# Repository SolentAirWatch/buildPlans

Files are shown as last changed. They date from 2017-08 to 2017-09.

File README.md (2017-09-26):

# buildPlans
build plans for sniffy and associated brackets. 

We're a little thin on documentation here - please help us out by submitting a pull request!

The works contained in this repositiory are licensed under the Creative Commons Attribution-NonCommercial-ShareAlike 4.0 International license (CC BY-NC-SA 4.0). This means you are free to share and share-alike for non-commercial use.




# Sniffy v1 Build Kit Assmebly

The sniffy kit containes the following: -

* 4x M4 x 12 barral bolts (#2)
* 4x M2 x 10 cheese head screws (#5)
* 4x self tapping screws (#3)
* 9x Nylon M3 x 10 cheese head screws 4x spacers (#1 & #6)
* 1x Back plate (drilled) (#7)
* 1x Enclosure (drilled) (not on photo)
* 1x 3D printed sensor cowling (#11)
* 1x Bosche BME280 environment sensor (temp, pressure, humdity) (#9)
* 1x Plantower PMS5003 Particulate Matter (PM) sensor (#10)
* 1x pi header to sensor cable

In addtion to the kit you will need:
* 1x Raspberry Pi Zero W
* Micro SD card (minimum 8 GB)
* Raspberry Pi Header (solderless headers are amvailable if you don't feel confident soldering)

These parts are shown in the photos below:
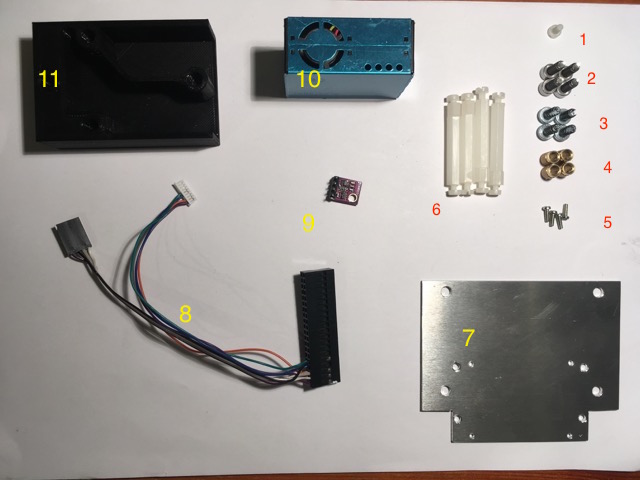
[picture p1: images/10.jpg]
Parts


* Insert the threads into the 3D printed sensor cowling 
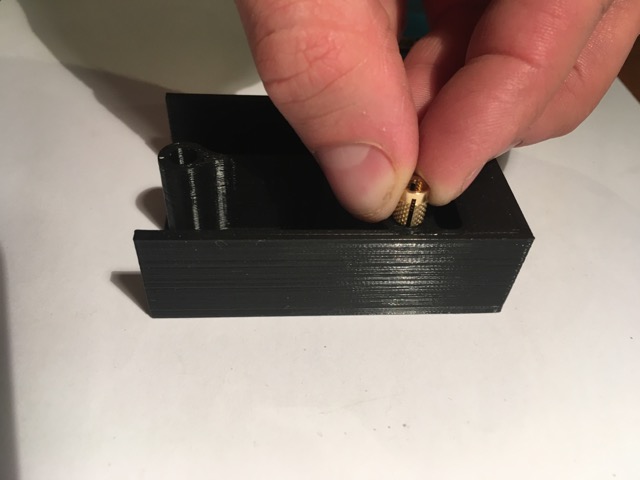
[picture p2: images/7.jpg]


* Use the M2 screws to mount the Pm sensor to the mounting place

* Use the nylon spacers and screws to mount the Raspbery Pi Zero above the PM sensor. You may need to widen the holes to 3mm but the nylon screws generally fit.

* Mount the assembly into the enclosure, fix the mounting plate using the self tapping screws

* Mount the BME280 sensor above the PM sensor using the remaining nylon screw into the threaded hole.
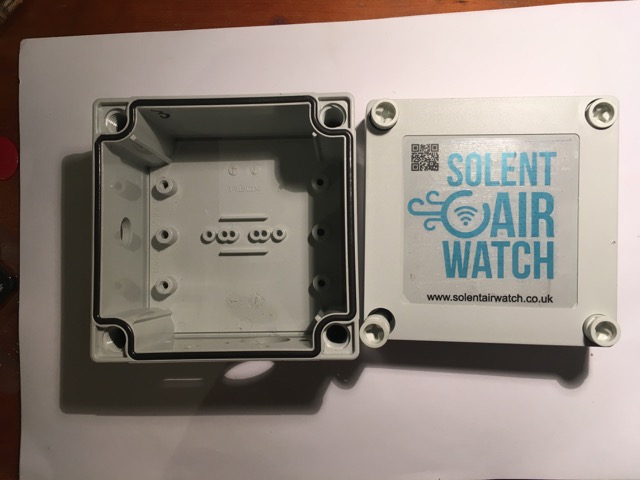
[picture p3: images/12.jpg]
box


* wire the sensor to the pi taking note of white marks denoting pin 1

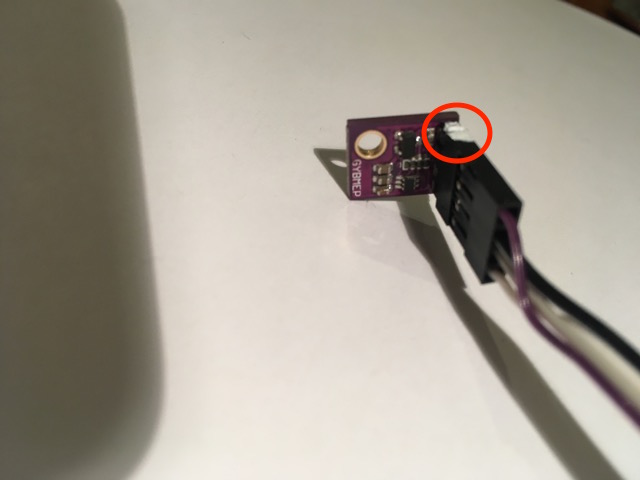
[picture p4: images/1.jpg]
BME280

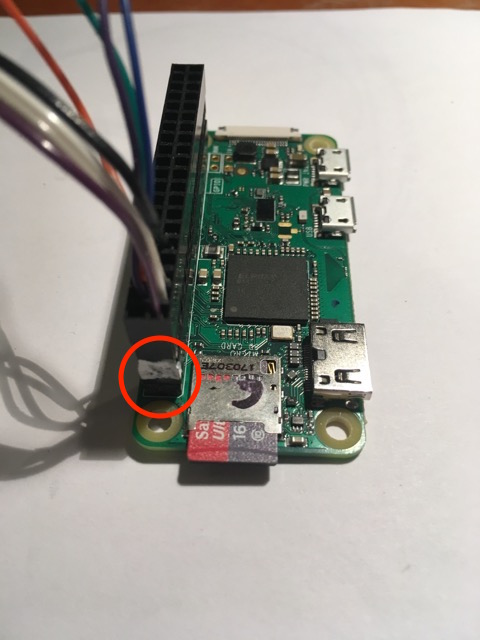
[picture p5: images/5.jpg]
RPi Header Pin 1


* Fit an SD card of at least 8GB and head over to /solentairwatcg/sniffy and follow the instructions to set up the raspberry pi and begin streaming data.

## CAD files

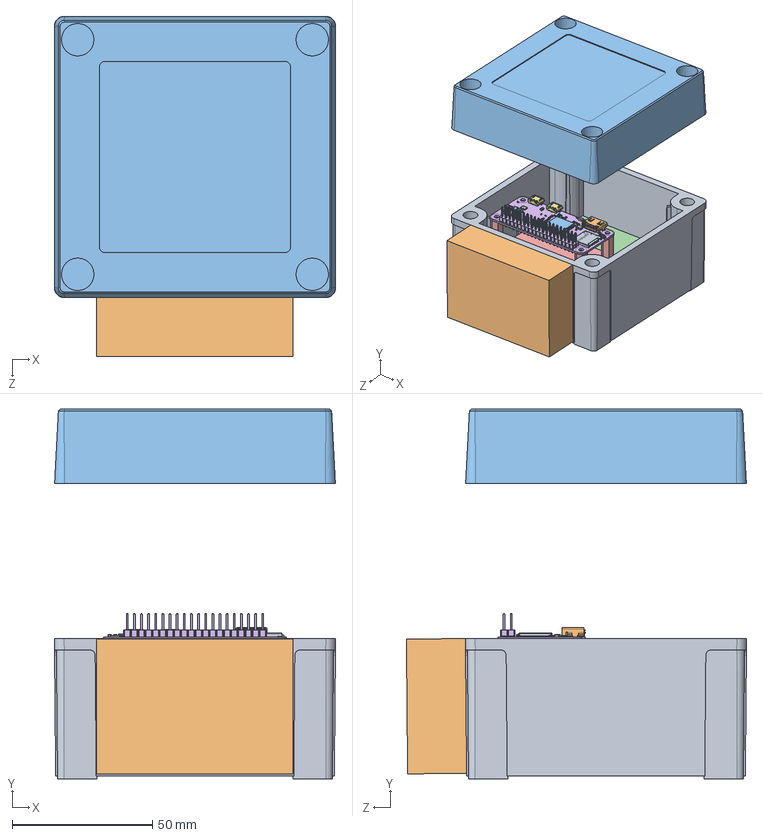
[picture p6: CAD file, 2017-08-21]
solidworks/sniffy_v1.SLDASM
100.1 x 131.7 x 121.1 mm
SNFY_003-FIBOX
SNFY_002-SensorCowling_2
SNFY_004-FIBOX-LID
SNFY005-backplate
SNF005 - pms5003
Raspberry_pizero_PCB
Micro USB_input_female (short)-SMT x 2
0204 - Capacitor x 34
0204- Resistor x 17
CAP-0306 x 2
Raspberry_pizero_BCM2835 with VC4
Crystal 3.4x2.4mm
32,768 Khz Crystal
0805- Capacitor x 7
0204 - Capacitor Brown x 8
6-Pin SOT
micro sd molex
hdmi type C
Voltage Regulator 3x3mm 12-Pin
1210 inductor x 3
SNFY009 - M3 hex standoff 36mm x 4
raspberry_pi_B+_(bar_180_2x20)

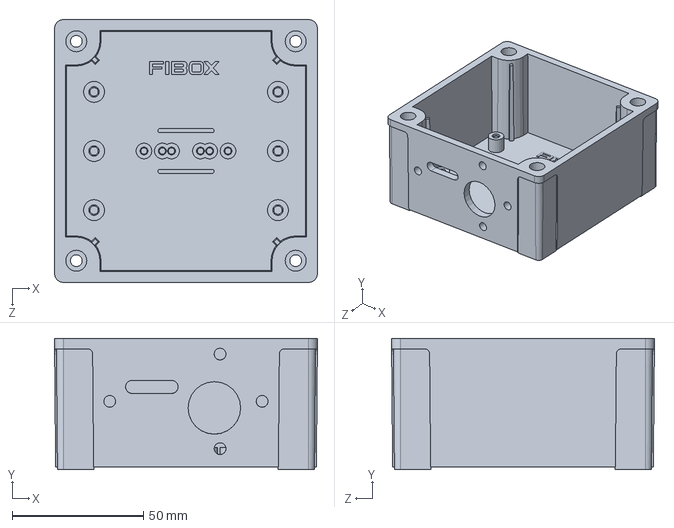
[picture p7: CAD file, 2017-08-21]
solidworks/SNFY_003-FIBOX.SLDPRT
100.1 x 50.0 x 100.1 mm

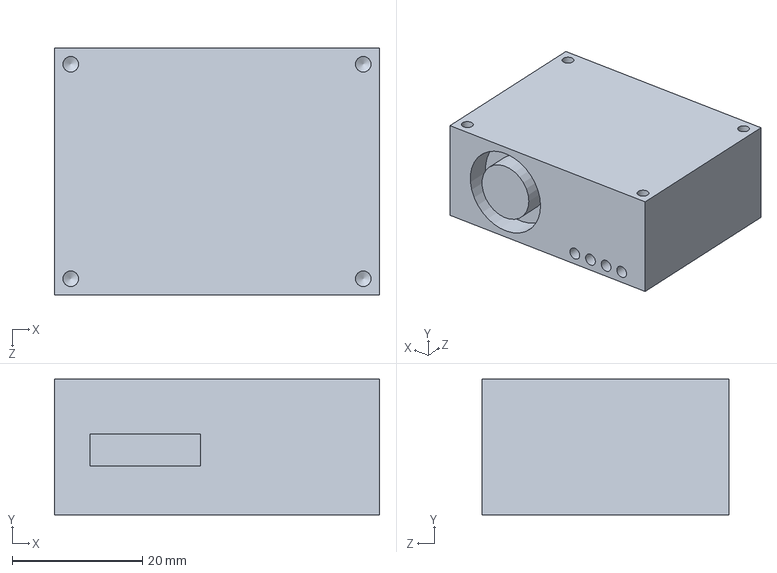
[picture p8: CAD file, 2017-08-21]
solidworks/SNF005 - pms5003.SLDPRT
50.0 x 20.9 x 38.0 mm

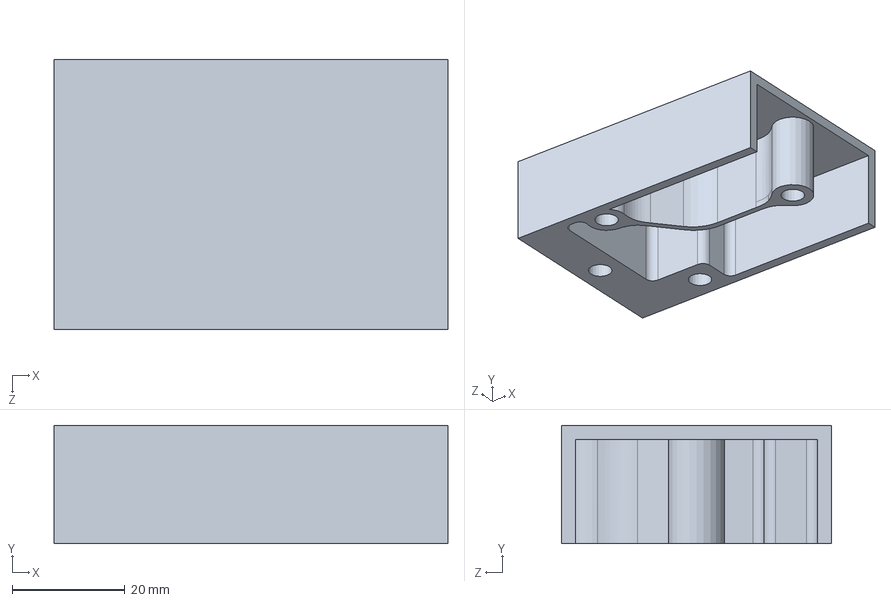
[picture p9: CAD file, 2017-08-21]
solidworks/SNFY_002-SensorCowling_2.SLDPRT
70.0 x 21.0 x 48.0 mm

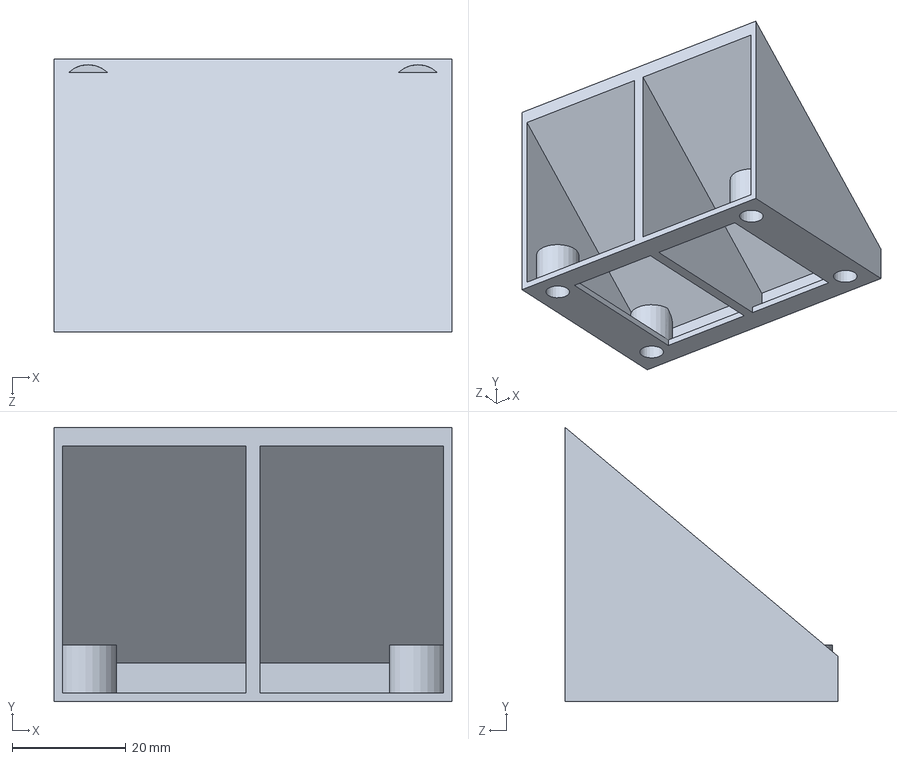
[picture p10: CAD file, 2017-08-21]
solidworks/SNFY_001-SensorCowling.SLDPRT
70.0 x 48.3 x 48.0 mm

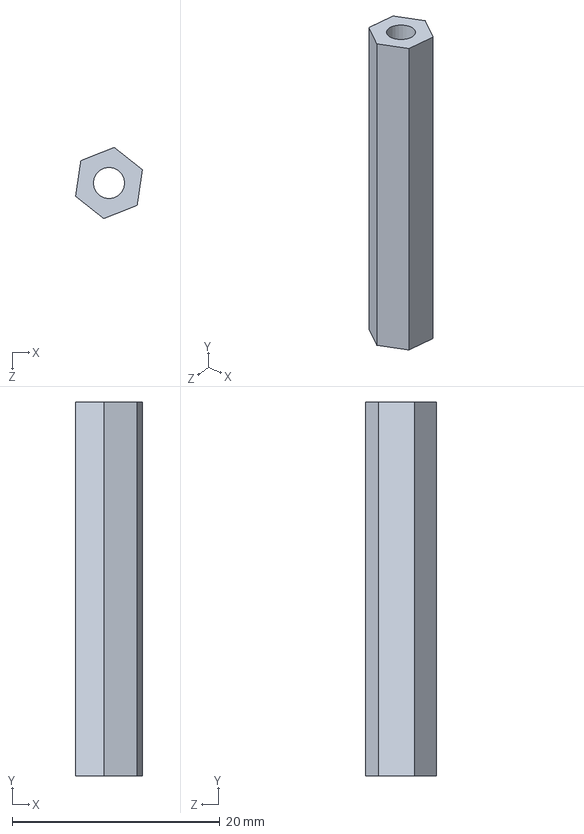
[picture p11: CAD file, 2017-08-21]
solidworks/SNFY009 - M3 hex standoff 26mm.SLDPRT
6.44 x 36.0 x 6.85 mm

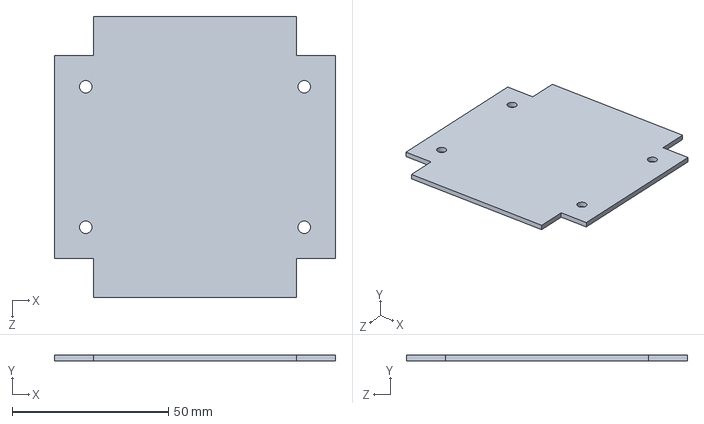
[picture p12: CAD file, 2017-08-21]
solidworks/SNFY005.SLDPRT
90.0 x 2.00 x 90.0 mm

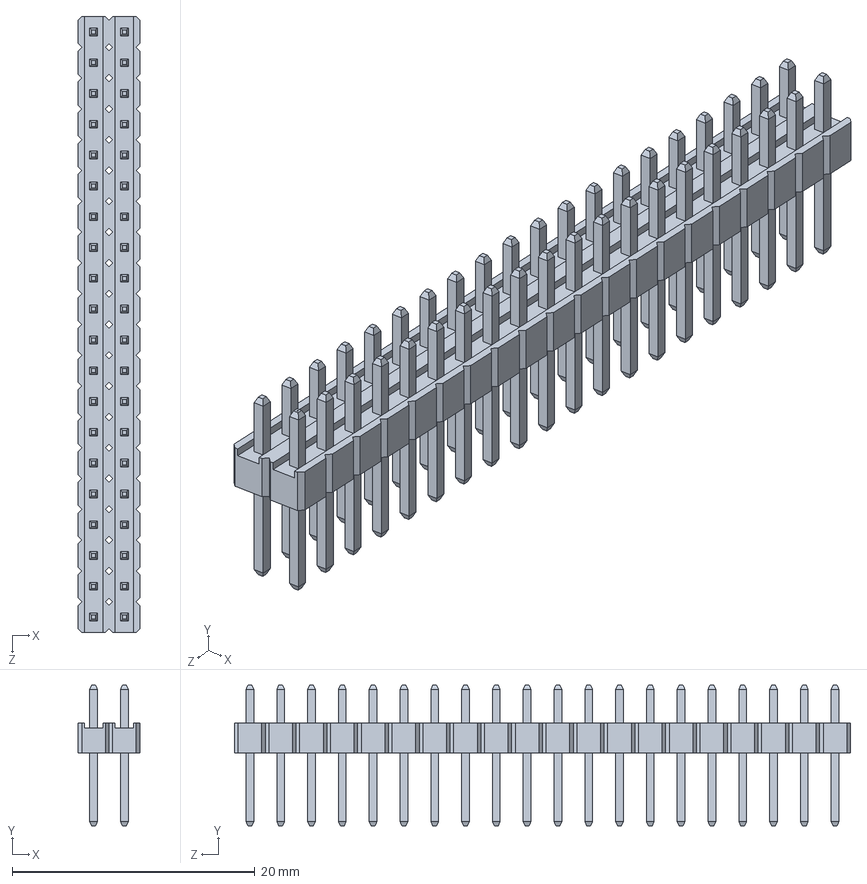
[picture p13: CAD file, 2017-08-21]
solidworks/raspberry_pi_B+_(bar_180_2x20).SLDPRT
5.08 x 11.6 x 50.8 mm

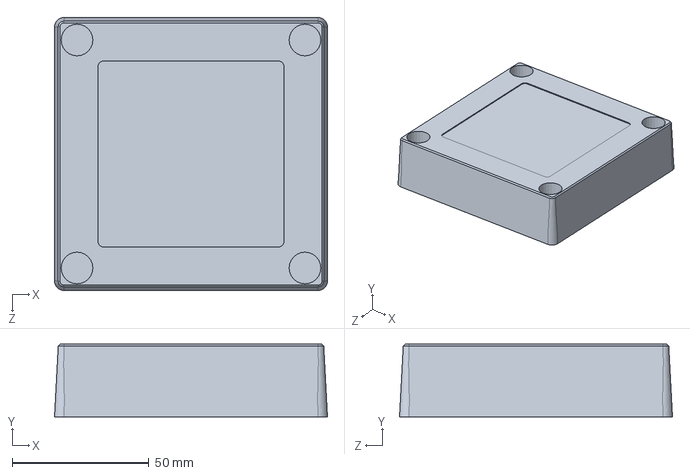
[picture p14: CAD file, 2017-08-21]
solidworks/SNFY_004-FIBOX-LID.SLDPRT
100.0 x 26.6 x 100.0 mm

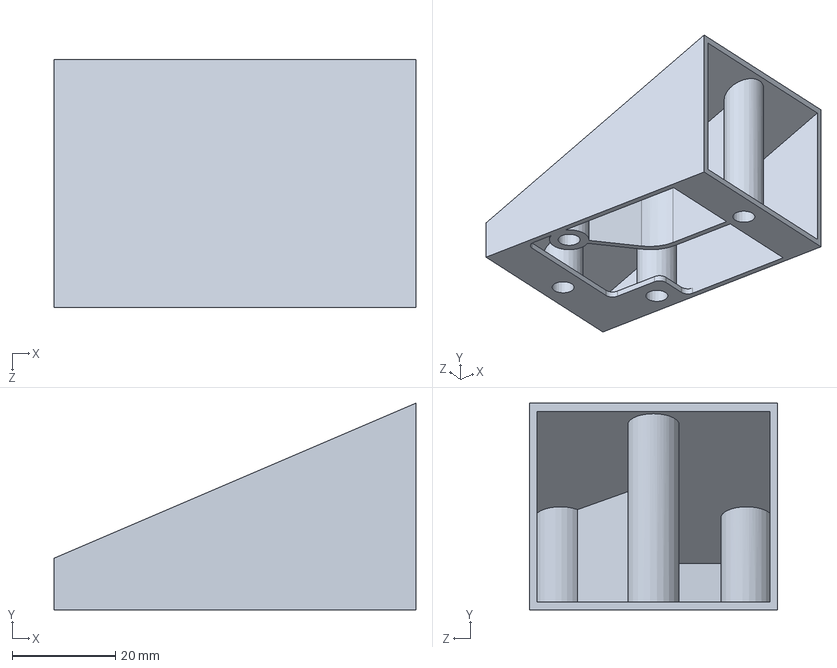
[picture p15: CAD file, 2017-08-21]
solidworks/SNFY_001-SensorCowling_2.SLDPRT
70.0 x 40.0 x 48.0 mm

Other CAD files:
solidworks/SNFY_002v3-SensorCowling-stl.SLDPRT
solidworks/SNFY009 - M3 hex standoff 36mm.SLDPRT
solidworks/SNFY005-backplate.SLDPRT
solidworks/SNFY005-backplate.SLDDRW
solidworks/SNFY_001-SensorCowling_2.SLDDRW
solidworks/SNFY_002-SensorCowling_2.SLDDRW
solidworks/SNFY_002-SensorCowling_2.STL
solidworks/SNFY_003-FIBOX.SLDDRW
solidworks/sniffy - exploded_view.SLDDRW

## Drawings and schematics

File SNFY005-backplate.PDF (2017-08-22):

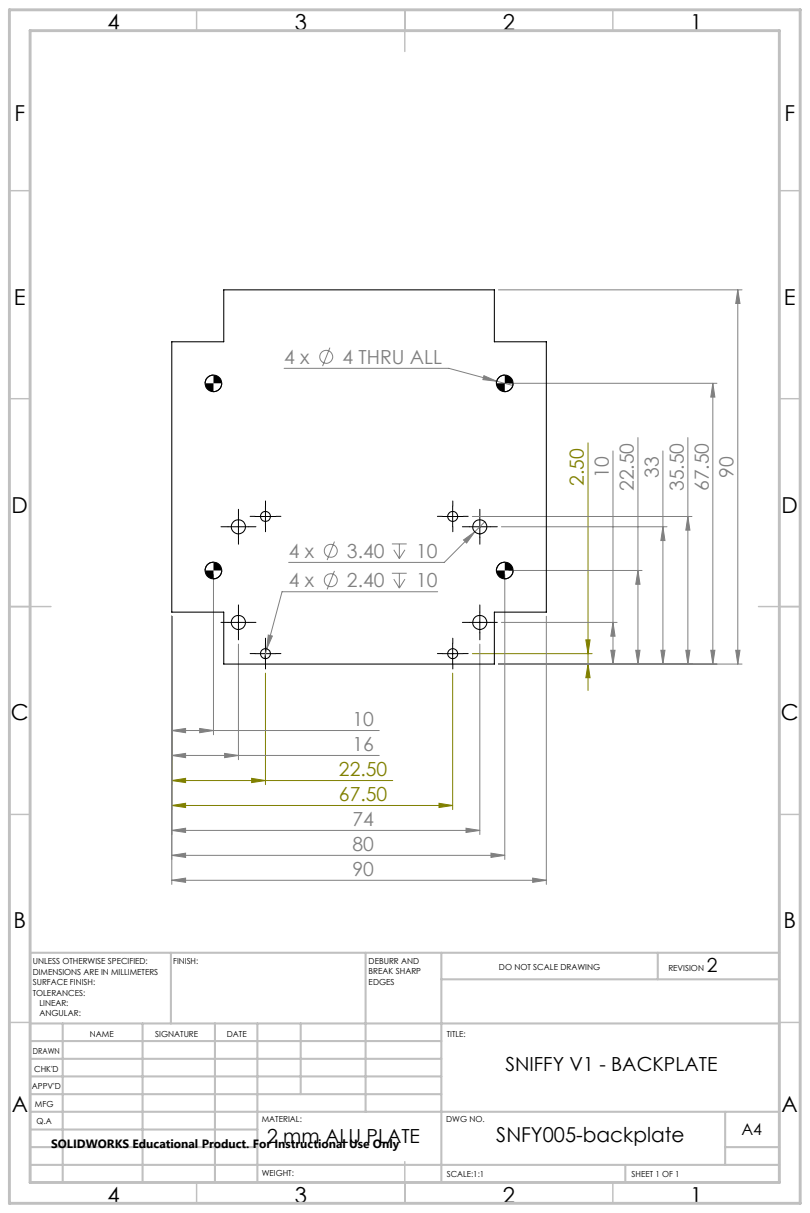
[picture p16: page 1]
4 THRU ALL; FINISH:; DEBURR AND; BREAK SHARP; DO NOT SCALE DRAWING; REVISION

UNLESS OTHERWISE SPECIFIED:
DIMENSIONS ARE IN MILLIMETERS
SURFACE FINISH:
TOLERANCES:
LINEAR:
ANGULAR:

NAME | SIGNATURE | DATE | TITLE:
SNIFFY V1 - BACKPLATE DRAWN
CHK'D
APPV'D
MFG
Q.A | MATERIAL: 2 mm ALU PLATE | DWG NO. SNFY005-backplate | A4
SOLIDWORKS Educational Product. For Instructional Use Only

WEIGHT: | | SCALE:1:1 | SHEET 1 OF 1

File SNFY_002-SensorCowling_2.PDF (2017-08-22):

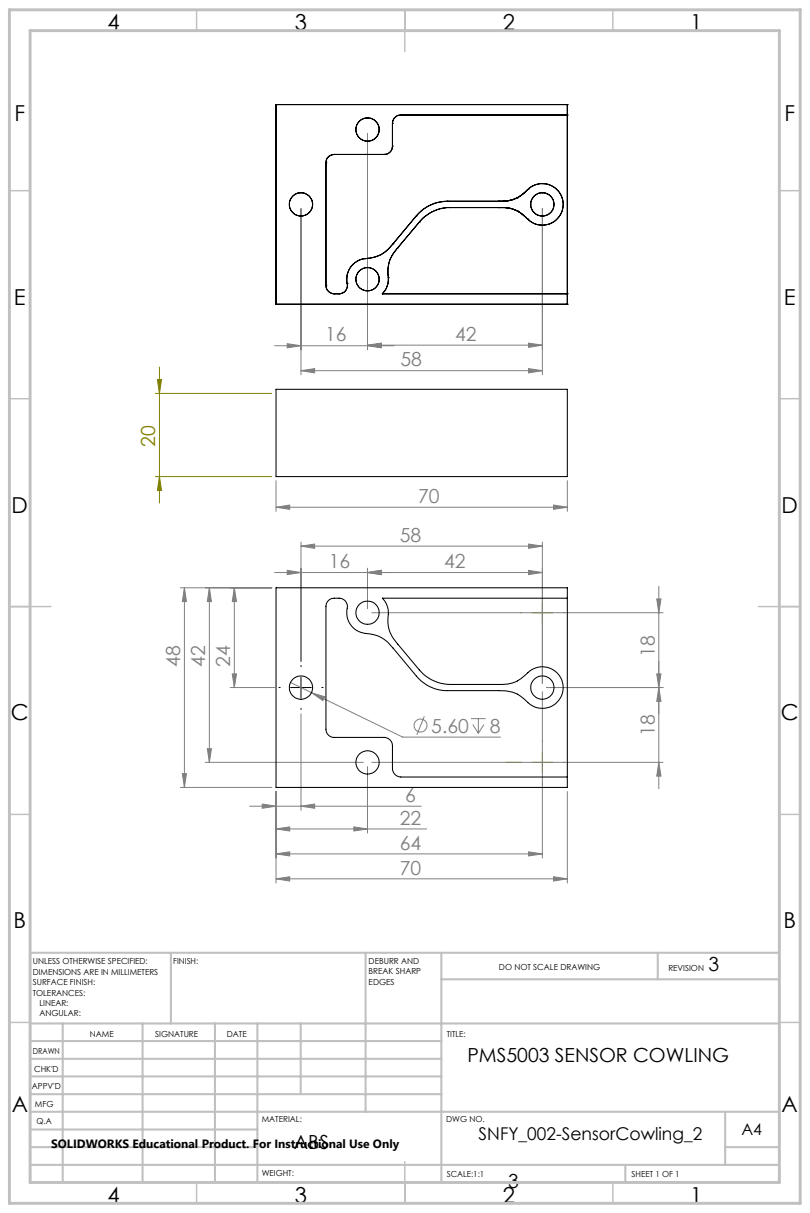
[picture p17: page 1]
FINISH:; DEBURR AND; BREAK SHARP; DO NOT SCALE DRAWING; REVISION

UNLESS OTHERWISE SPECIFIED:
DIMENSIONS ARE IN MILLIMETERS
SURFACE FINISH:
TOLERANCES:
LINEAR:
ANGULAR:

NAME | SIGNATURE | DATE | | | | TITLE:
DRAWN | | | | | | | PMS5003 SENSOR COWLING CHK'D

APPV'D
MFG
Q.A | | | | MATERIAL: ABS | DWG NO. SNFY_002-SensorCowling_2 | A4
SOLIDWORKS Educational Product. For Instructional Use Only

WEIGHT: | | SCALE:1:1 | SHEET 1 OF 1

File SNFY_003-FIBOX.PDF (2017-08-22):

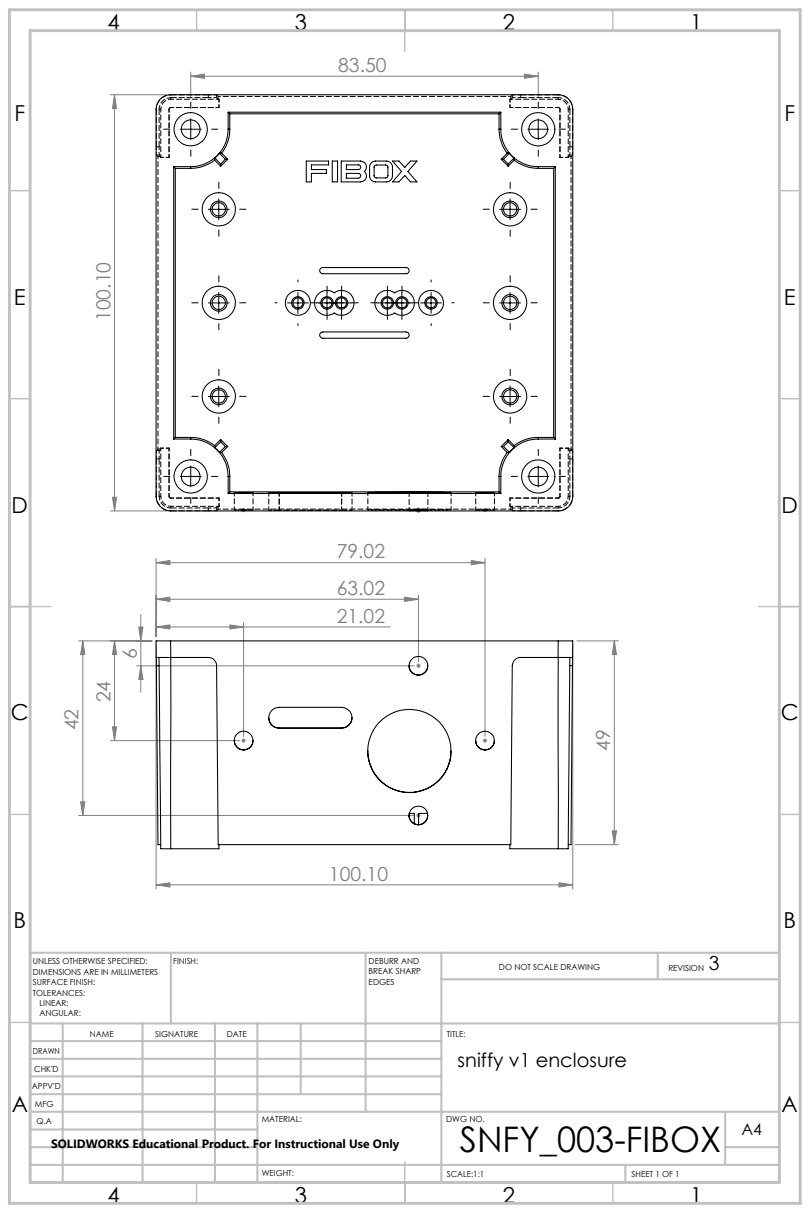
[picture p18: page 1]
FINISH:; DEBURR AND; BREAK SHARP; DO NOT SCALE DRAWING; REVISION

UNLESS OTHERWISE SPECIFIED:
DIMENSIONS ARE IN MILLIMETERS
SURFACE FINISH:
TOLERANCES:
LINEAR:
ANGULAR:

NAME | SIGNATURE | DATE | TITLE:
sniffy v1 enclosure DRAWN
CHK'D
APPV'D
MFG
Q.A | MATERIAL: | DWG NO. SNFY_003-FIBOX | A4
SOLIDWORKS Educational Product. For Instructional Use Only

WEIGHT: | | SCALE:1:1 | SHEET 1 OF 1

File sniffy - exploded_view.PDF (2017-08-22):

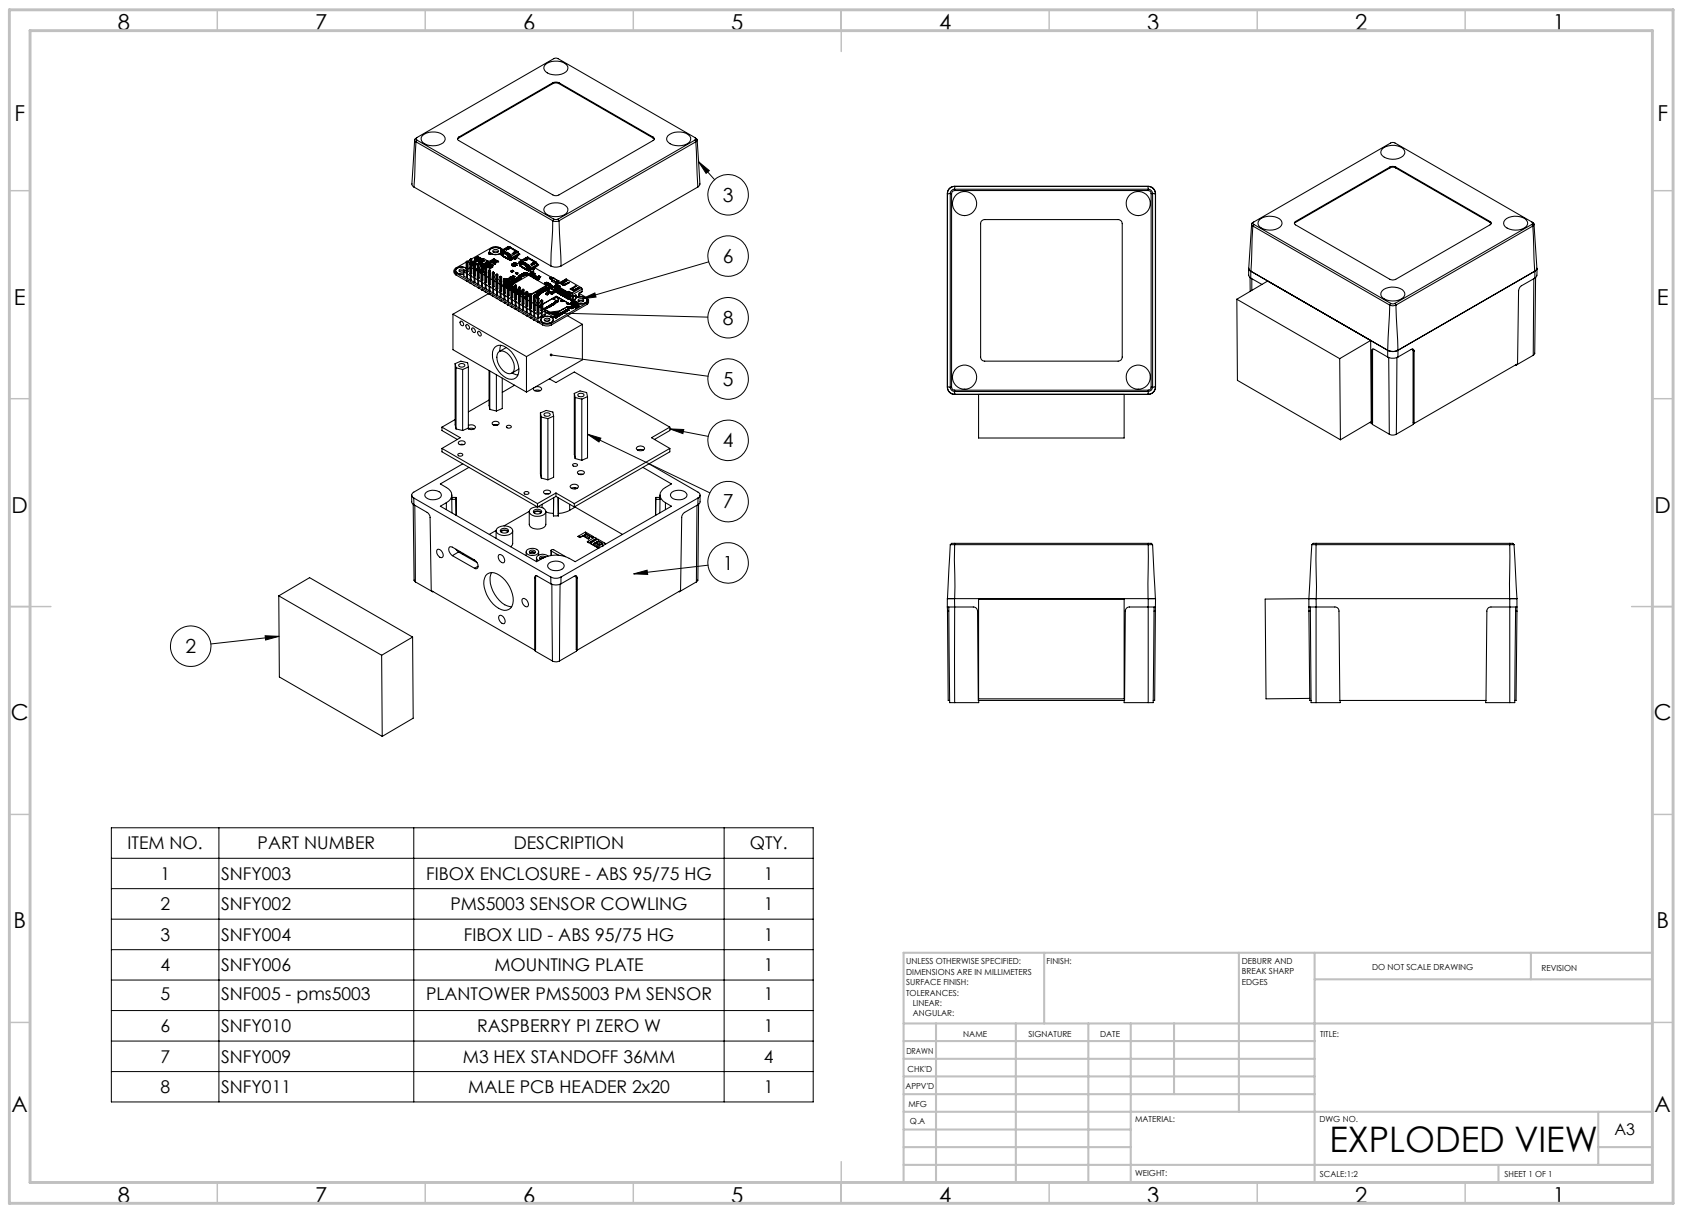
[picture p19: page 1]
SNFY006; MOUNTING PLATE; SNFY009; M3 HEX STANDOFF 36MM; FINISH:; DEBURR AND; BREAK SHARP; DO NOT SCALE DRAWING; REVISION; SCALE:1:2; SHEET 1 OF 1

ITEM NO. | PART NUMBER | DESCRIPTION | QTY.
1 | SNFY003 | FIBOX ENCLOSURE - ABS 95/75 HG | 1
2 | SNFY002 | PMS5003 SENSOR COWLING | 1
3 | SNFY004 | FIBOX LID - ABS 95/75 HG | 1

UNLESS OTHERWISE SPECIFIED:
DIMENSIONS ARE IN MILLIMETERS
SURFACE FINISH:
TOLERANCES:
LINEAR:
ANGULAR:

5 | SNF005 - pms5003 | PLANTOWER PMS5003 PM SENSOR | 1
6 | SNFY010 | RASPBERRY PI ZERO W | 1

NAME | SIGNATURE | DATE | TITLE:

CHK'D
APPV'D
MFG
Q.A | MATERIAL: | DWG NO. EXPLODED VIEW | A3

8 | SNFY011 | MALE PCB HEADER 2x20 | 1

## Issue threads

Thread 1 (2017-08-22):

Bosch BME280 environmental sensor missing in drawings

joshctaylor, 2017-08-22:
needs to be added

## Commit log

2017-08-21 adding solidworks files
    [SNF005 - pms5003.SLDPRT, SNFY005-backplate.SLDDRW, SNFY005-backplate.SLDPRT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]
2017-08-22 add drawing file for exploded view
    [sniffy - exploded_view.SLDDRW]
